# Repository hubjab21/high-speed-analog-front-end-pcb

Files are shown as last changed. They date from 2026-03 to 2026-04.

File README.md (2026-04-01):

# LMH5401 Differential Amplifier

High-speed differential amplifier designed using **LMH5401** for RF / ADC front-end applications.

---

## Overview

This project presents the design, simulation, implementation, and measurement of a **low-noise fully differential amplifier** intended for high-frequency signal processing.

The circuit is based on the **LMH5401**, a wideband amplifier capable of operating up to GHz frequencies, commonly used in communication, radar, and data acquisition systems.

---

## Objectives

- Design a high-speed differential amplifier
- Achieve high gain (~40 dB target)
- Maintain wide bandwidth
- Ensure proper impedance matching (RF domain)
- Validate performance through simulations and measurements

---

## Simulation (LTspice)

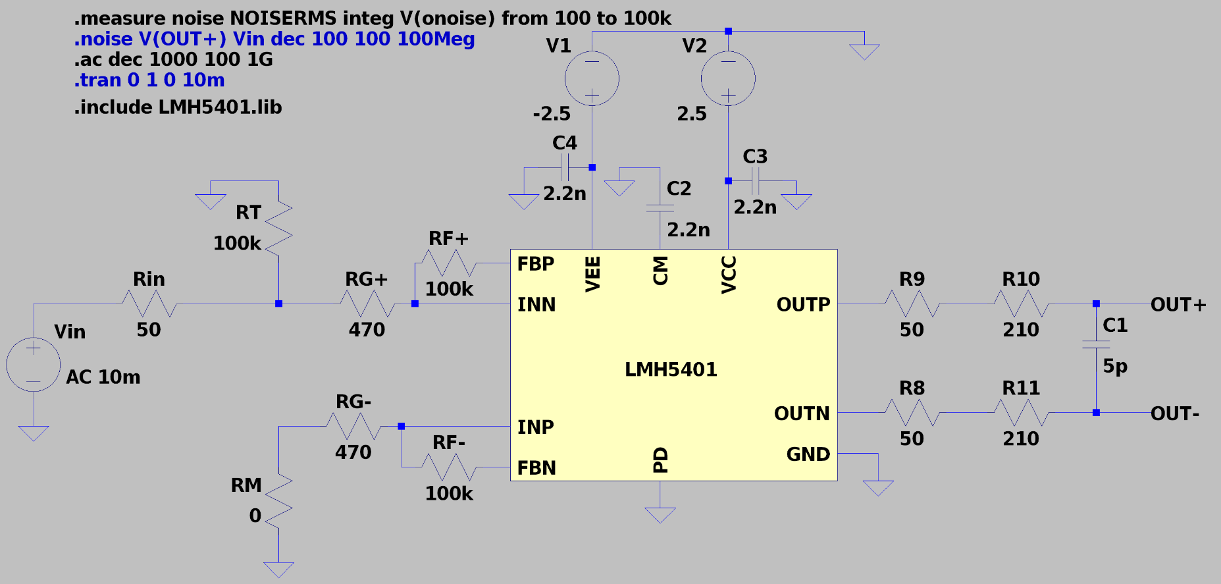
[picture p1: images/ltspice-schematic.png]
LTspice


LTspice simulation (version 26) was used to:

- select feedback resistor values 
- verify circuit stability 
- estimate gain and frequency response 
- evaluate output noise performance 

Version is available from the Analog Devices website: <br>
https://www.analog.com/en/resources/design-tools-and-calculators/ltspice-simulator.html <br><br> 

The main page provides access to LTspice 26 is available in the downloads section (access verified on 02.04.2026).

---

### LTspice Setup

Simulation files are located in:

```
LTspice/
```

Contents:

- `lmh5401_test.asc` – main simulation schematic
- `LMH5401.lib` – SPICE model
- `LMH5401.asy` – LTspice symbol

---

### SPICE Model (Download)

The LMH5401 SPICE model and symbol used in this project are based on files provided by **Texas Instruments**.

Official product page:
https://www.ti.com/product/LMH5401

Direct download (SPICE model):
https://www.ti.com/lit/zip/sbombp6

The download link was verified as accessible on **30.03.2026**.

---

### Simulation Directives

```spice
.ac dec 1000 100 1G
.tran 0 1 0 10m
.noise V(OUT+) Vin dec 100 100 100Meg
.measure noise NOISERMS integ V(onoise) from 100 to 100k
```

---

## Design

### Schematic (KiCad)

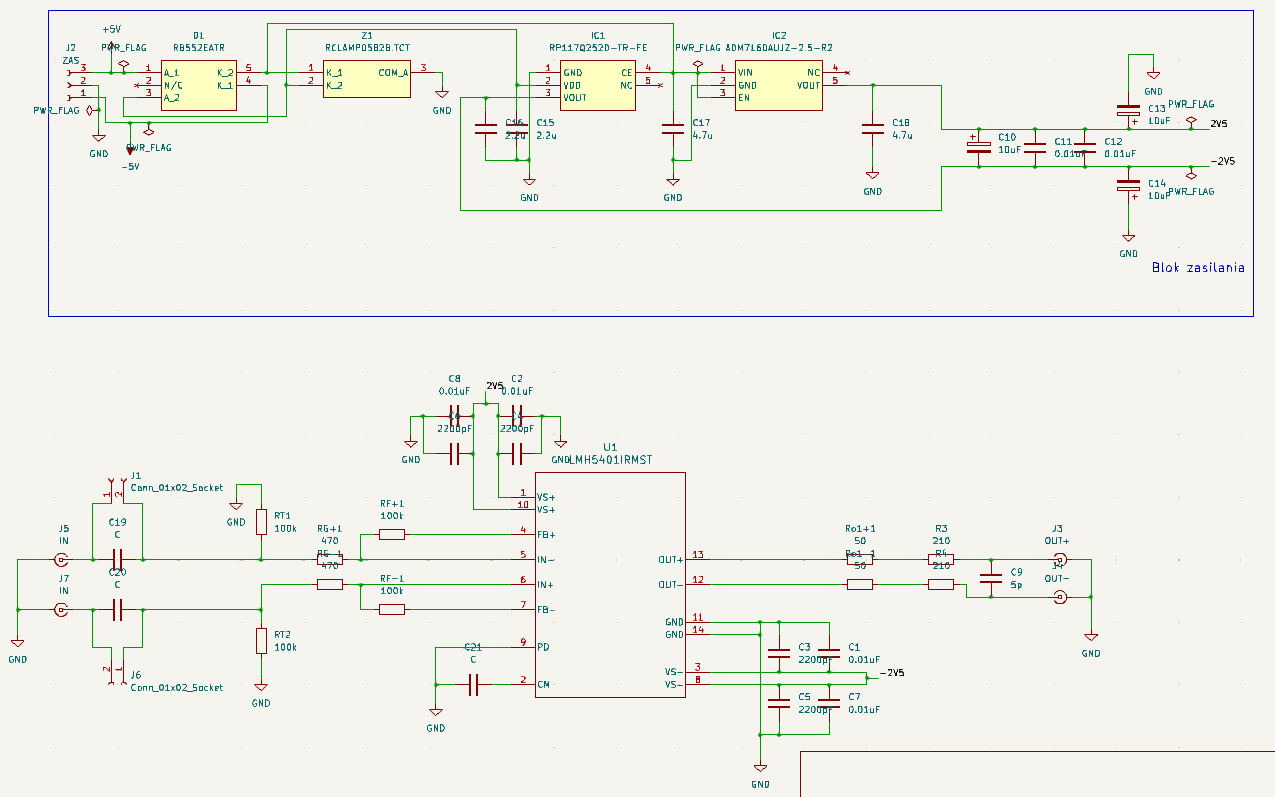
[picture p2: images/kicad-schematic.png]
Schematic


### 3D View

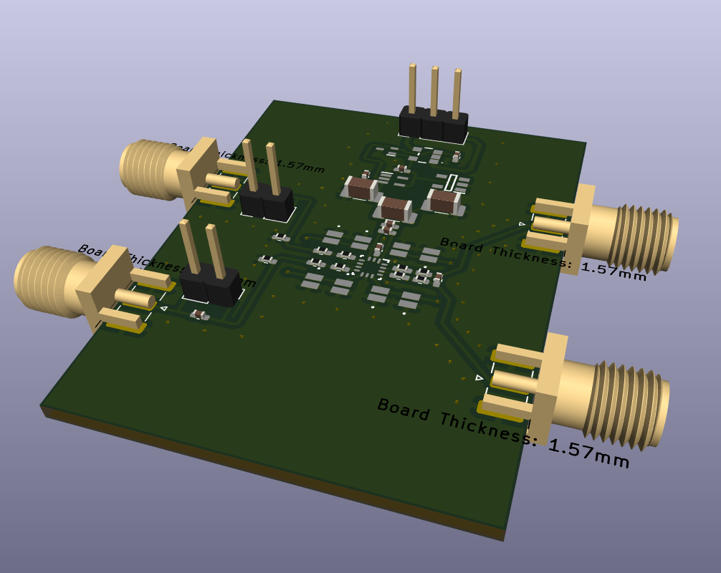
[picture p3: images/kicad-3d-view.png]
3D PCB


### PCB Layout

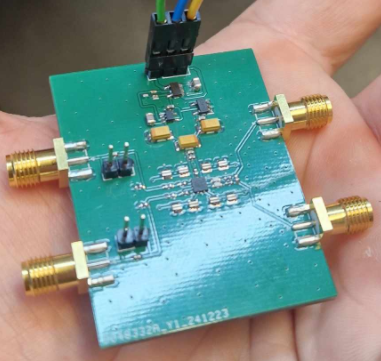
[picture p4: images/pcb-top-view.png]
PCB


---

## Equipment

* Rigol DSA815 – Spectrum Analyzer
* Rigol MSO5204 – Oscilloscope
* Siglent SDG2122X – Signal Generator

---

## Experimental Results

### Signal Generator Setup

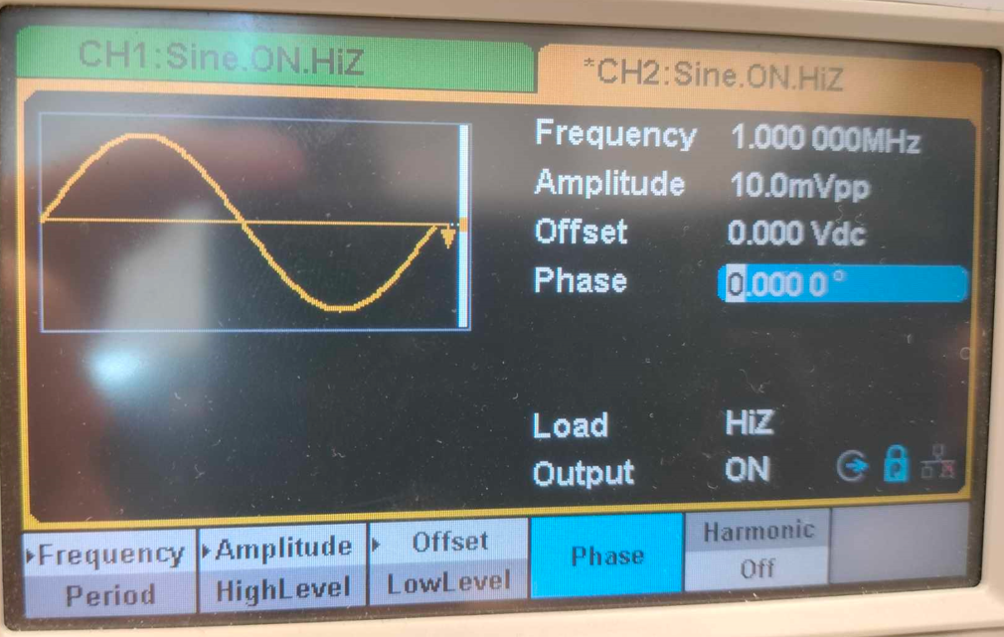
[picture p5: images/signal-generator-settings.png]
Generator


- Frequency: **1 MHz**
- Amplitude: **10 mVpp**
- Differential signal (180° phase shift)

---

### Oscilloscope Output

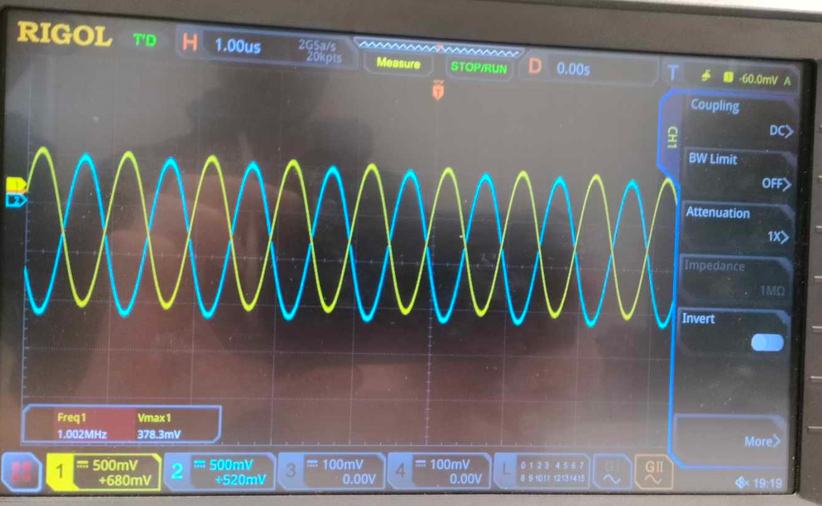
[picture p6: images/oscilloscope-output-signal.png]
Oscilloscope


- Measured gain: **~68× (~36.6 dB)**
- Proper differential operation
- 180° phase shift between outputs

---

## Results

- Measured gain: **~36.65 dB**
- Target gain: **~40 dB**
- Effective bandwidth: **~3.7 MHz**

This is significantly lower than the expected GHz-range bandwidth of the LMH5401, indicating strong influence of:

- PCB parasitics
- impedance mismatch
- non-RF layout constraints

---

## Key Findings

- The amplifier operates correctly in differential mode
- Gain is close to expected values
- Bandwidth is significantly reduced compared to theoretical assumptions

---

## Improvements

- Improve RF impedance matching (50 Ω design)
- Optimize PCB layout (shorter traces, controlled impedance)
- Use high-frequency optimized passive components
- Perform S-parameter simulations
- Reduce parasitic capacitances

---

## Project Structure

```
├── bom/
│   └── ibom.html
├── images/
├── LTspice/
│   ├── LMH5401.asy
│   ├── LMH5401.lib
│   └── lmh5401_test.asc
├── manufacturing/
│   └── Gerber.zip
├── Projekt_AUE.csv
├── Projekt_AUE.kicad_pcb
├── Projekt_AUE.kicad_pro
├── Projekt_AUE.kicad_sch
└── README.md
```

---

## Authors

- Hubert Jabłoński
- Jakub Domin
- Wojciech Broda

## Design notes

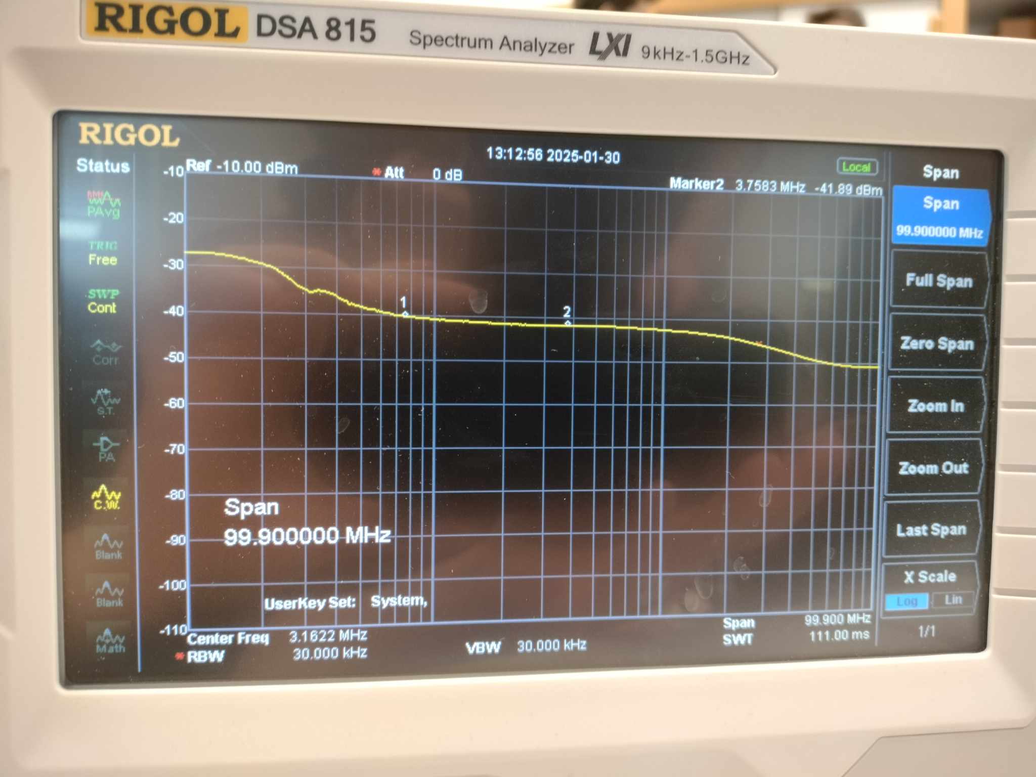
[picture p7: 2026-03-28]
images/spectrum-noise-input.png

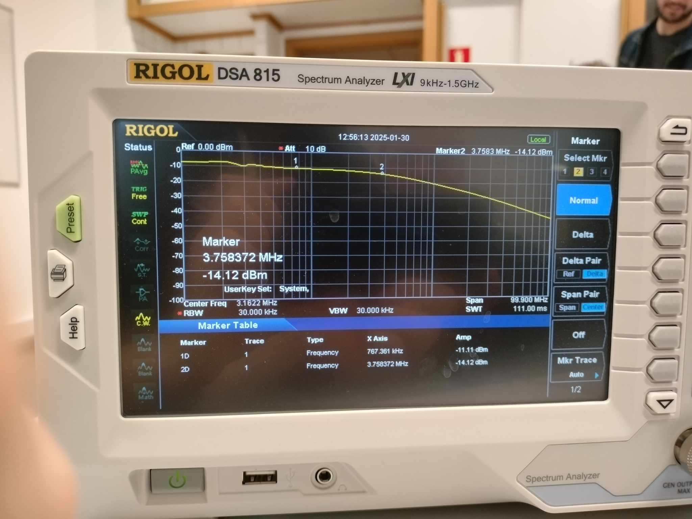
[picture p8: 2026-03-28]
images/spectrum-amplified-signal.png

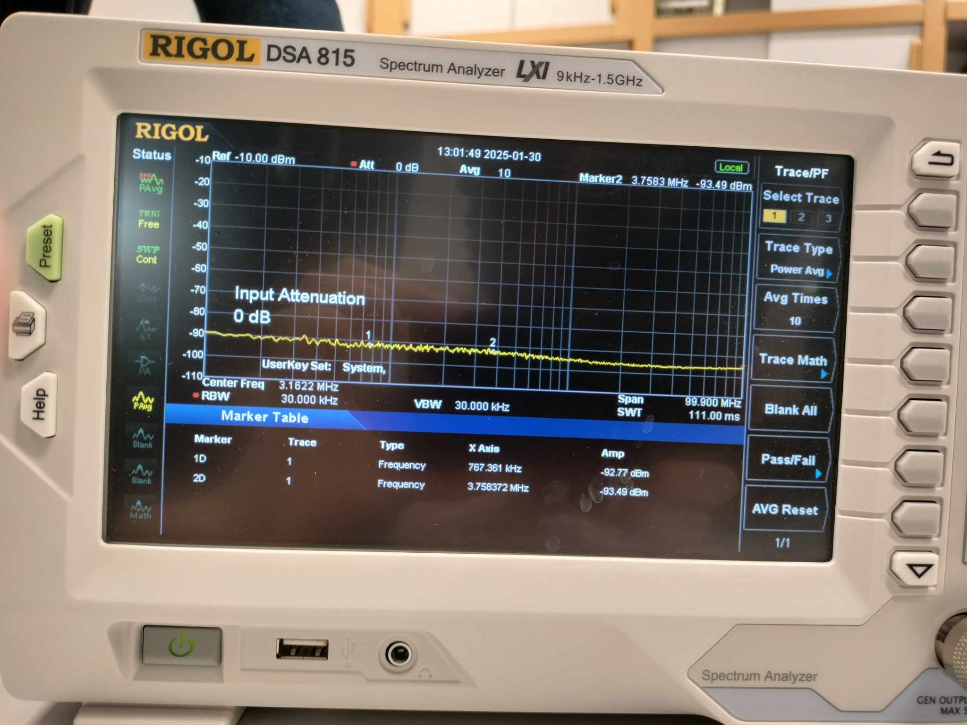
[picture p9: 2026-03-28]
images/spectrum-baseline.png

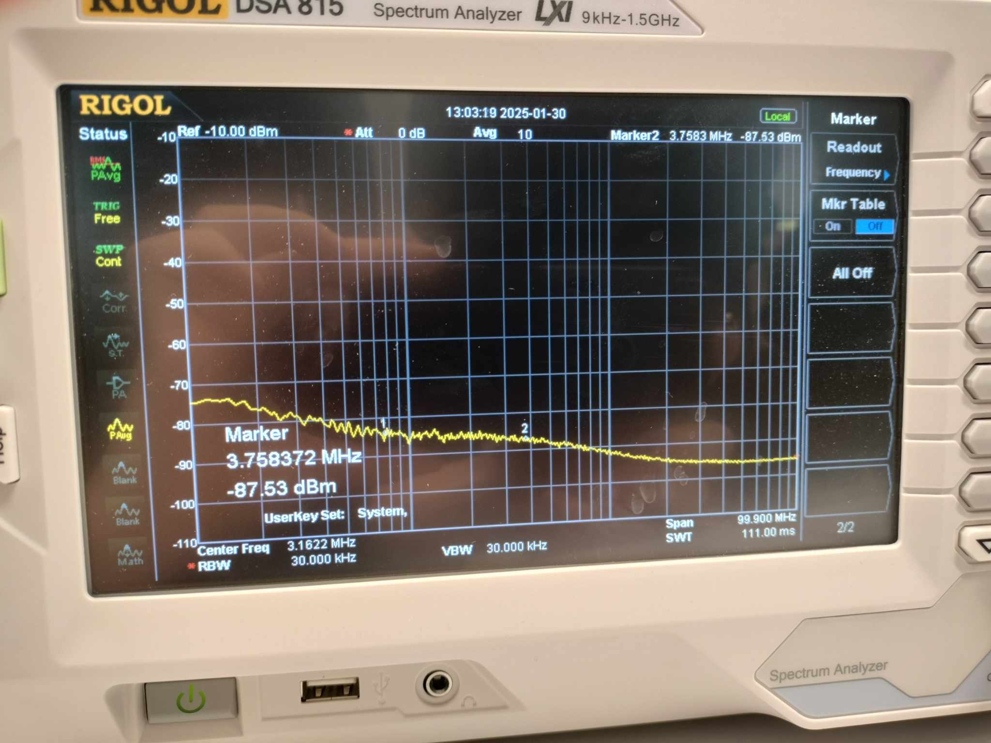
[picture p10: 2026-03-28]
images/spectrum-noise-output.png

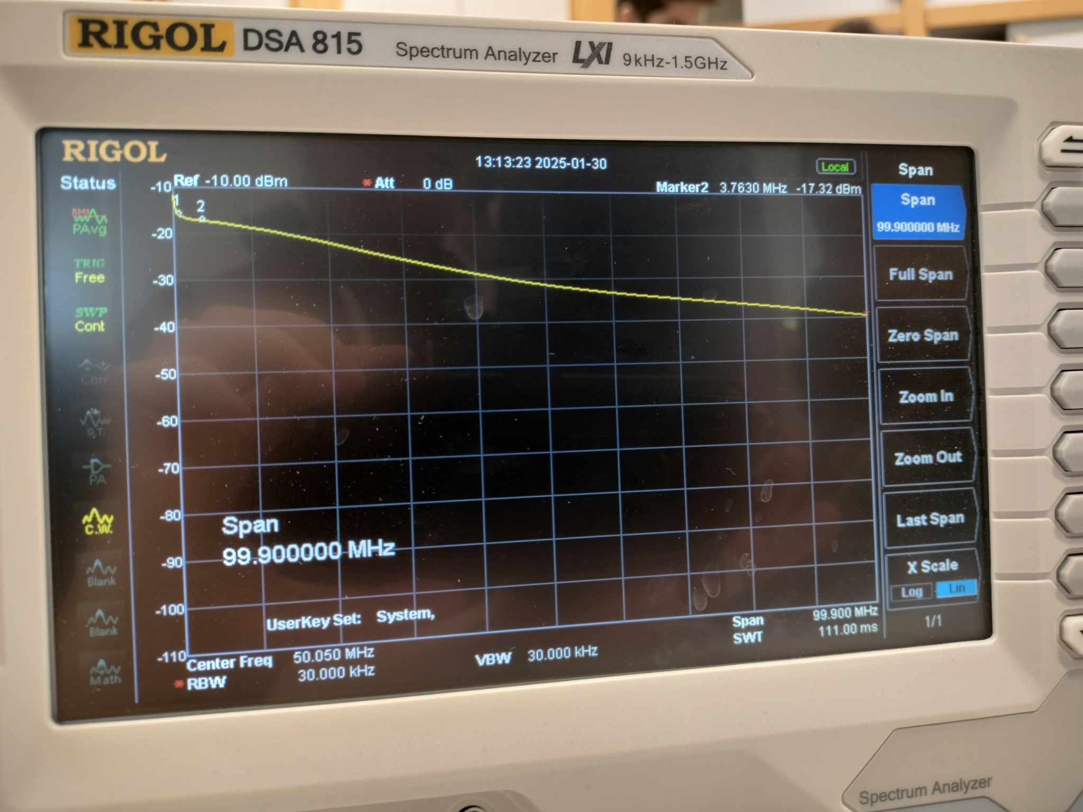
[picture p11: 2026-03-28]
images/frequency-response.png

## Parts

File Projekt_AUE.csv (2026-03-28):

Reference | Value | Datasheet | Footprint | Qty | DNP
C1,C2,C7,C8,C11,C12 | 0.01uF | ~ | -- różne wartości -- | 6
C3,C4,C5,C6 | 2200pF | ~ | footprints:LLL18_MUR-M | 4
C9 | 5p | ~ | Capacitor_SMD:C_0402_1005Metric_Pad0.74x0.62mm_HandSolder | 1
C10,C13,C14 | 10uF | ~ | Capacitor_SMD:C_1206_3216Metric_Pad1.33x1.80mm_HandSolder | 3
C15,C16 | 2.2u | ~ | Capacitor_SMD:C_0402_1005Metric_Pad0.74x0.62mm_HandSolder | 2
C17,C18 | 4.7u | ~ | Capacitor_SMD:C_0402_1005Metric_Pad0.74x0.62mm_HandSolder | 2
C19,C20,C21 | C | ~ | Capacitor_SMD:C_0402_1005Metric_Pad0.74x0.62mm_HandSolder | 3
D1 | RB552EATR | https://fscdn.rohm.com/en/products/databook/datasheet/discrete/diode/schottky_barrier/rb552eatr-e.pdf | footprints:RB552EATR | 1
IC1 | RP117Q252D-TR-FE | https://www.nisshinbo-microdevices.co.jp/en/pdf/datasheet/rp117-ea.pdf | footprints:SOT65P210X110-5N | 1
IC2 | ADM7160AUJZ-2.5-R2 | https://componentsearchengine.com/Datasheets/2/ADM7160AUJZ-2.5-R2.pdf | footprints:SOT95P280X100-5N | 1
J1,J6 | Conn_01x02_Socket | ~ | Connector_PinHeader_2.54mm:PinHeader_1x02_P2.54mm_Vertical | 2
J2 | ZAS | ~ | Connector_PinHeader_2.54mm:PinHeader_1x03_P2.54mm_Vertical | 1
J3 | OUT+ | ~ | Connector_Coaxial:SMA_Samtec_SMA-J-P-H-ST-EM1_EdgeMount | 1
J4 | OUT- | ~ | Connector_Coaxial:SMA_Samtec_SMA-J-P-H-ST-EM1_EdgeMount | 1
J5,J7 | IN | ~ | Connector_Coaxial:SMA_Samtec_SMA-J-P-H-ST-EM1_EdgeMount | 2
R3,R4 | 210 | ~ | Resistor_SMD:R_0402_1005Metric | 2
RF+1,RF-1,RT1,RT2 | 100k | ~ | Resistor_SMD:R_0402_1005Metric_Pad0.72x0.64mm_HandSolder | 4
RG+1,RG-1 | 470 | ~ | Resistor_SMD:R_0402_1005Metric_Pad0.72x0.64mm_HandSolder | 2
Ro1+1,Ro1-1 | 50 | ~ | Resistor_SMD:R_0402_1005Metric_Pad0.72x0.64mm_HandSolder | 2
U1 | LMH5401IRMST | LMH5401IRMST | footprints:RMS0014A | 1
Z1 | RCLAMP0582B.TCT | https://datasheet.datasheetarchive.com/originals/distributors/DKDS-37/728243.pdf | footprints:SOT50P160X90-3N | 1

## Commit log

2026-03-28 Initial commit - LMH5401 differential amplifier project
    [Projekt_AUE.csv, Projekt_AUE.kicad_pcb, Projekt_AUE.kicad_sch]
2026-03-30 feat: add LTspice simulation files and update README (schematic image, documentation improvements)
